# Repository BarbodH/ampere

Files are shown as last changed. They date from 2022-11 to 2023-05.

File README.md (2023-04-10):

# Ampere

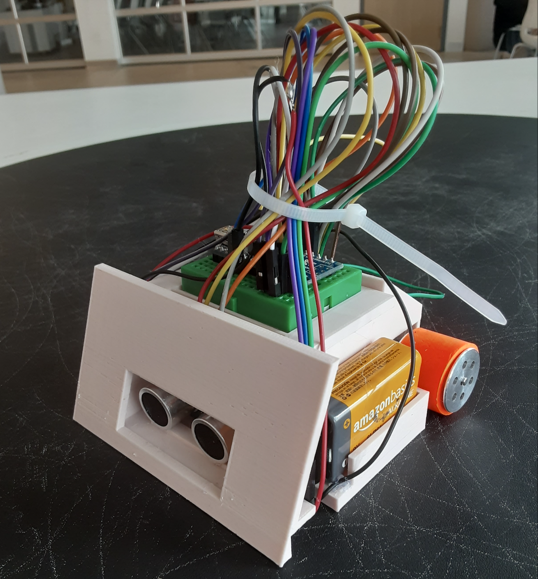
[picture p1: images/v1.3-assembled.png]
[](/images/v1.3-assembled.png)

Ampere is a self-driving 10×10 cm robot designed for [robot-sumo competitions](https://www.sumobot.ca/competition), analogous to the sport of sumo.

## Components

The robot utilizies the following pieces of electronic hardware:

  - [Arduino Nano](components/arduino-nano-v3.stl) (1×): main control unit using an ATmega328 microcontroller
  - [HC-SR04 ultrasonic sensor](components/hcsr04-ultrasonic-sensor.stl) (1×): utilized for detecting the opponent and initiating an attack
  - [QTR-1A reflectance sensor](components/qtr1a-reflectance-sensor.stl) (2×): utilized for keeping the robot inside the field using the floor color
  - [L298N motor driver](components/l298n-motor-driver.stl) (1×): utilized for controlling the movement of the 6V DC motors
  - [JSumo 6V DC motor](components/jsumo-dc-motor.stl) (2×): connect to the motor driver and handle mobility
  - 9V battery (2×): provide power for the robot

## Functionality

The functionality of the robot is divided into 3 layers of abstraction (ordered from lowest to highest):

  1. Libraries dealing with digital/analog input/output to the electronic hardware
      - [HC-SR04 ultrasonic sensor library](libraries/HCSR04_ultrasonic_sensor); developed by [gamegine](https://github.com/gamegine)
      - [QTR-1A reflectance sensor library](libraries/QTR1A_Reflectance_Sensor_Library); developed by me
      - [L298N motor driver library](libraries/L298N_Motor_Driver_Library); developed by me
  
  2. System classes providing a liaison between the microcontroller and hardware libraries through signals:
      - [Navigation system](microcontroller/NavigationSystem.h): utilizes the sensors to handle edge/opponent detection and produces boolean signals
      - [Motion control system](microcontroller/MotionControlSystem.h): utilizes the motor driver to handle various movement types

3. [Microcontroller](microcontroller/microcontroller.ino) Arduino file controlling the behaviour

Writing the entire program in the **microcontroller.ino** is also feasible.
However, dividing the program into multiple abstraction layers allows for better readability and debugging.

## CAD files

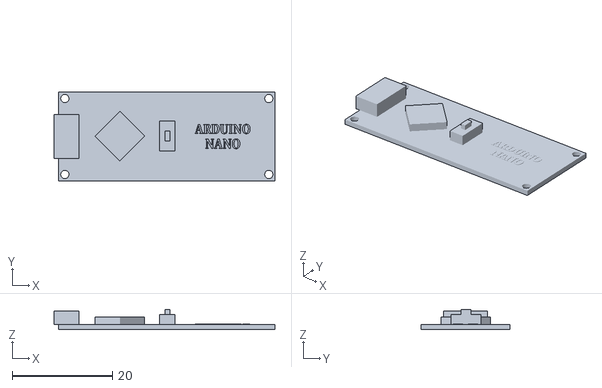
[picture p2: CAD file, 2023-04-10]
components/arduino-nano-v3.stl
44.1 x 17.8 x 4.00

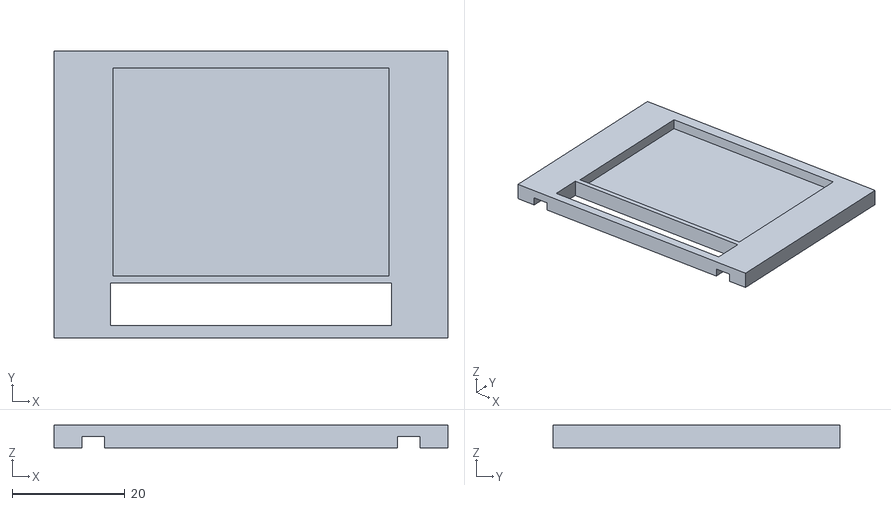
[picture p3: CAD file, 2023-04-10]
components/chassis/v1.4/roof.stl
70.0 x 51.0 x 4.00

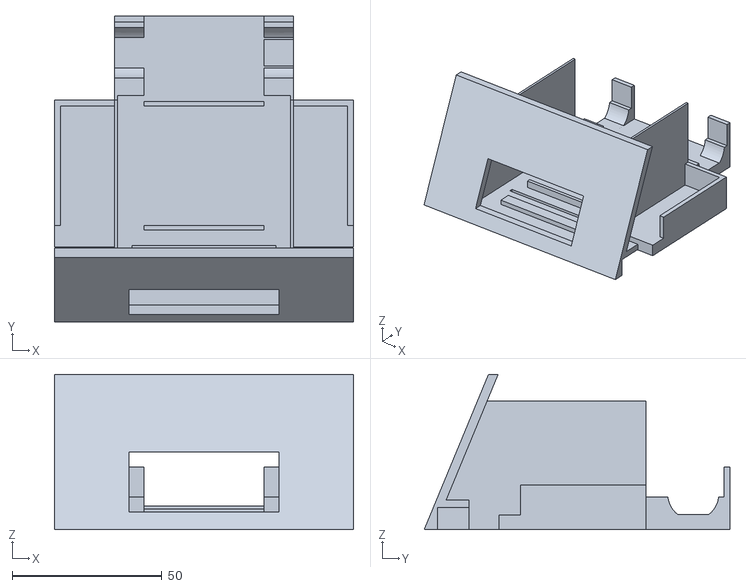
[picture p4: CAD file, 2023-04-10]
components/chassis/v1.4/chassis.stl
100.0 x 102.3 x 52.0

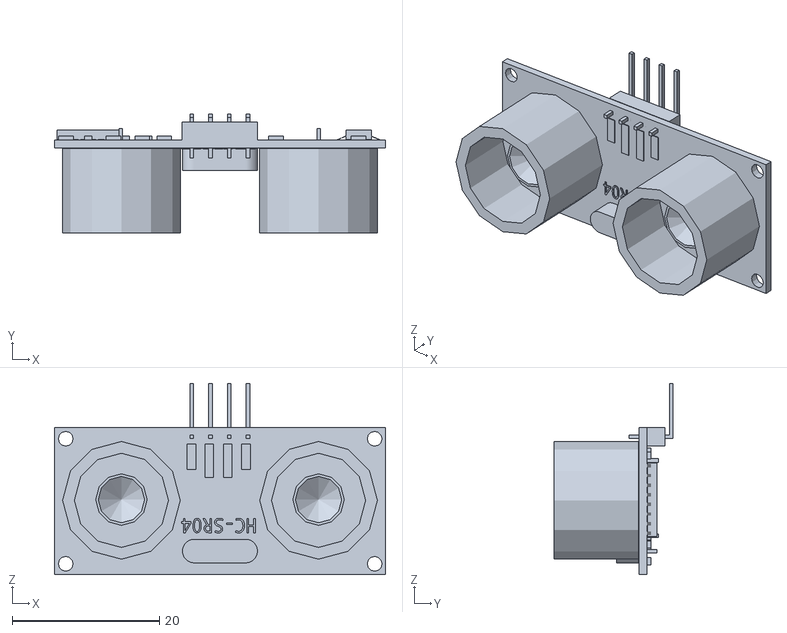
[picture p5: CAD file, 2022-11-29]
components/hcsr04-ultrasonic-sensor.stl
45.0 x 16.2 x 26.0

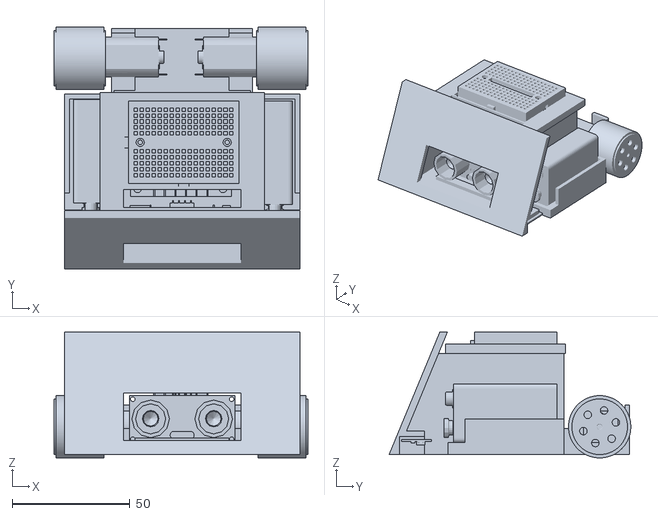
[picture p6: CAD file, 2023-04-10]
components/chassis/v1.4/sumobot.stl
108.0 x 102.8 x 53.5

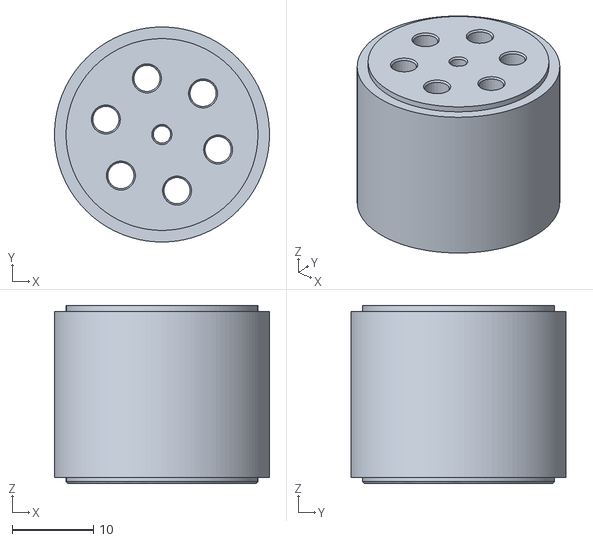
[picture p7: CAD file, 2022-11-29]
components/js7444-wheel.stl
26.5 x 26.5 x 22.0

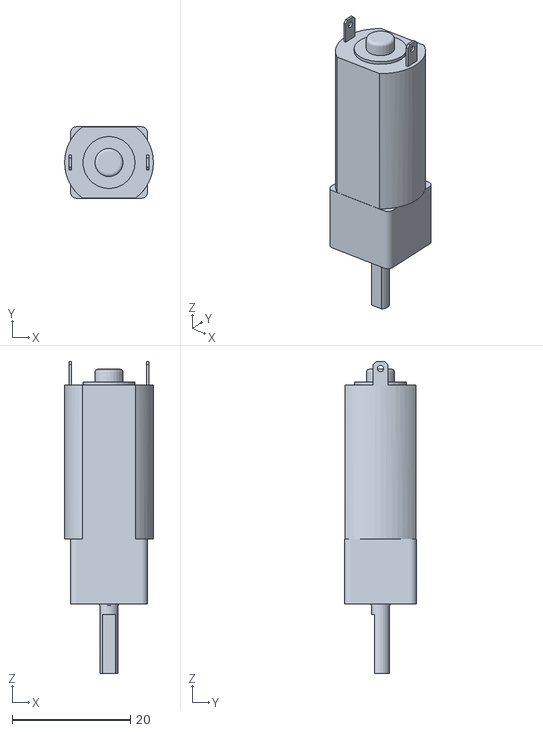
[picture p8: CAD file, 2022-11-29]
components/jsumo-dc-motor.stl
15.0 x 12.1 x 52.7

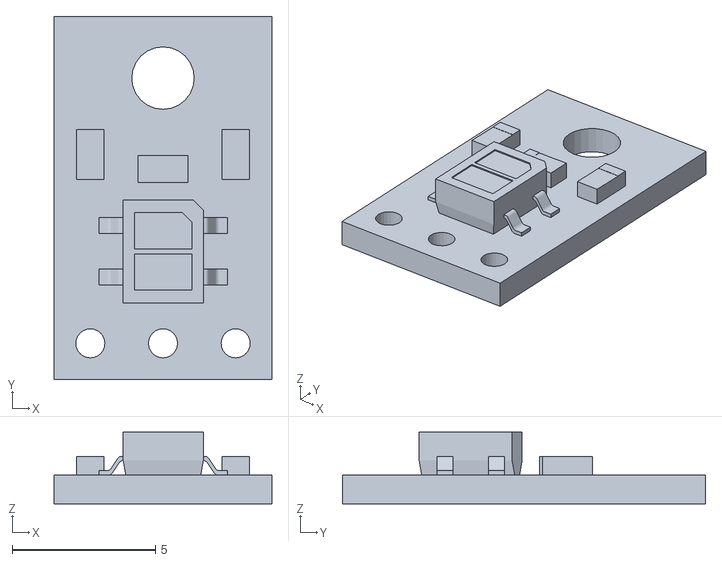
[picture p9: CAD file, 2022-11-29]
components/qtr1a-reflectance-sensor.stl
7.62 x 12.7 x 2.52

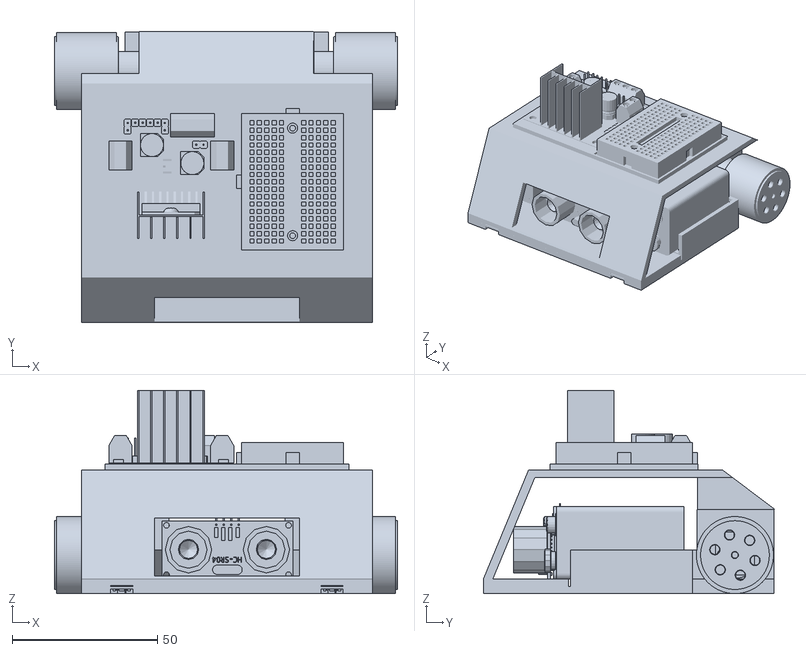
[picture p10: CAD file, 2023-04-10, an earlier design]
components/chassis/v1.0/sumobot.stl
118.0 x 100.2 x 69.9

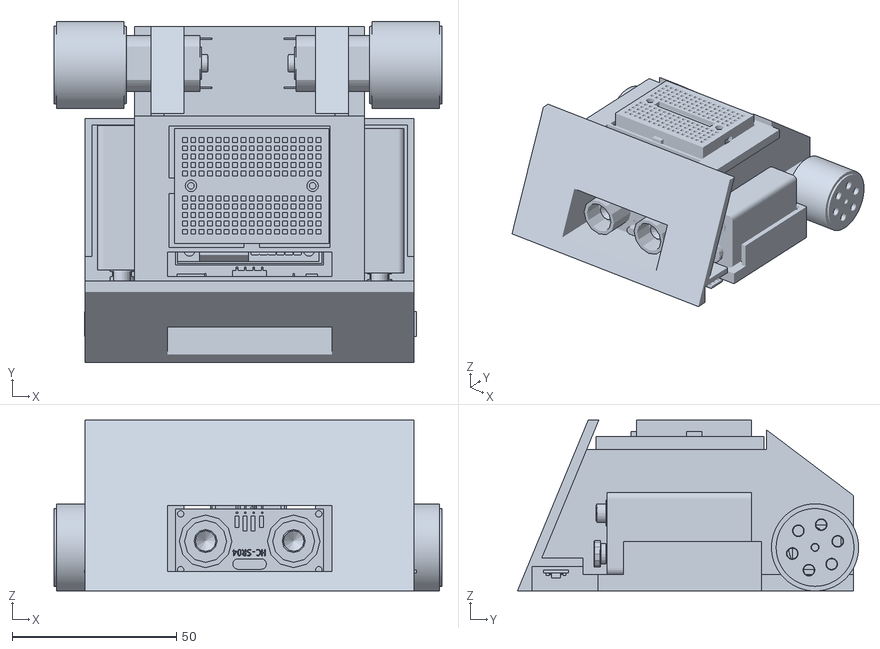
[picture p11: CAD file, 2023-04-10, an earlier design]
components/chassis/v1.1/sumobot.stl
118.0 x 103.8 x 52.0

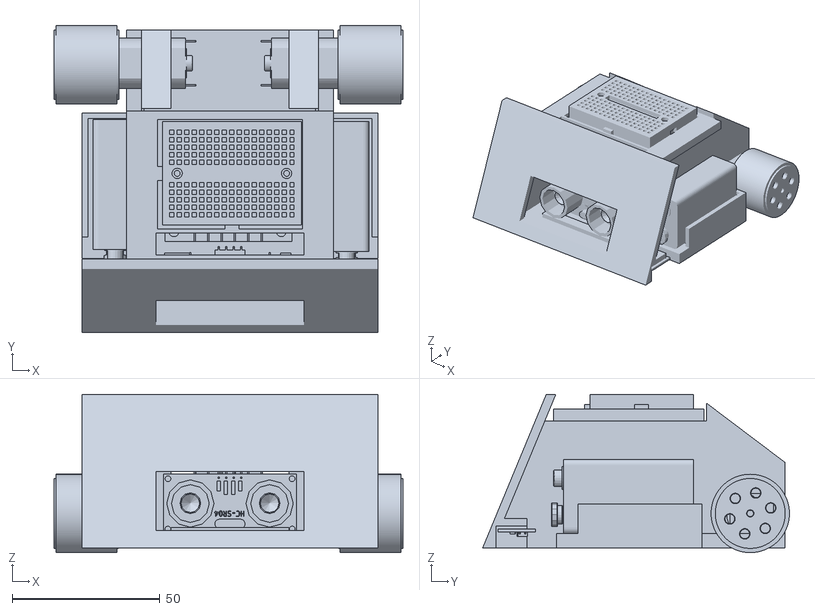
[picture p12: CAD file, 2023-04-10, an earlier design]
components/chassis/v1.2/sumobot.stl
118.0 x 103.8 x 53.5

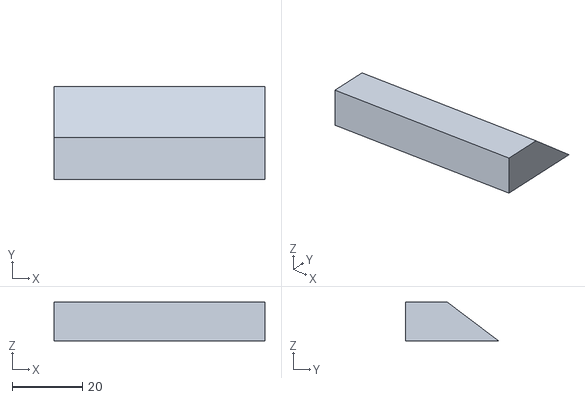
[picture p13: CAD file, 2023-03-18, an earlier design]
components/chassis/v1.0/roof-support.stl
60.0 x 26.5 x 11.0

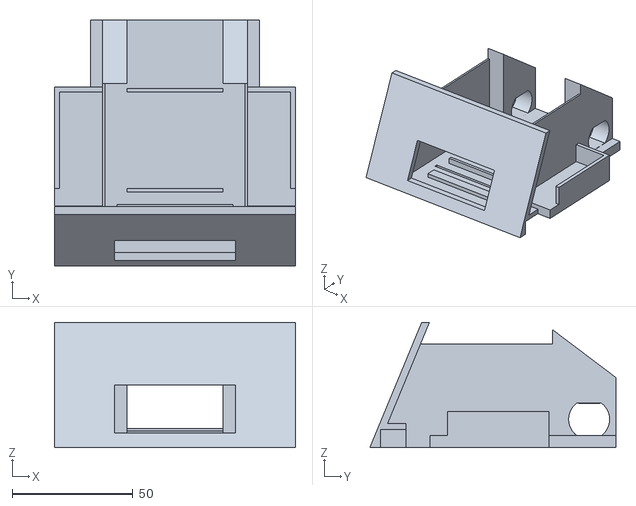
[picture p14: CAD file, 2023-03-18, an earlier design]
components/chassis/v1.2/chassis.stl
100.0 x 102.3 x 52.0

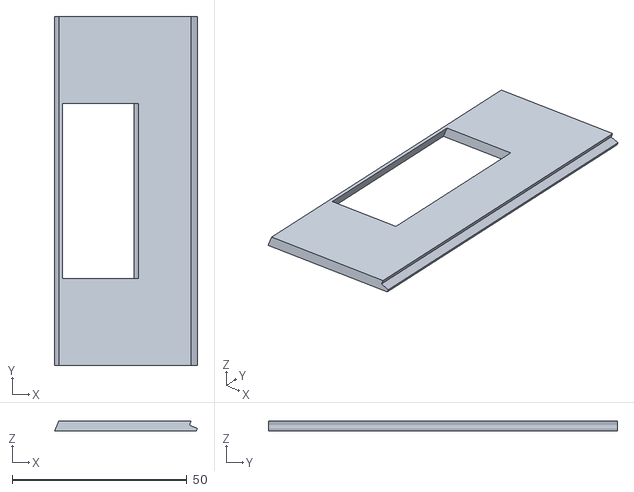
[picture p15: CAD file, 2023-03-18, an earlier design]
components/chassis/v1.0/front.stl
40.9 x 100.0 x 3.00

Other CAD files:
components/chassis/v1.3/sumobot.stl
components/chassis/v1.1/roof.stl
components/chassis/v1.3/roof.stl
components/chassis/v1.1/chassis.stl
components/chassis/v1.0/chassis.stl
components/chassis/v1.0/front-support.stl
components/chassis/v1.0/roof.stl
components/chassis/v1.2/roof.stl
components/chassis/v1.3/chassis.stl

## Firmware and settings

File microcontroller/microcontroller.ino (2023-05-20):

//////////////////// Control Systems ////////////////////

#include "NavigationSystem.h"
#include "MotionControlSystem.h"

//////////////////// Initialization ////////////////////

// macro-defined constants for pin values
#define PIN_ENABLE_A 2
#define PIN_ENABLE_B 3
#define PIN_INPUT_1 4
#define PIN_INPUT_2 5
#define PIN_INPUT_3 6
#define PIN_INPUT_4 7
#define TRIG_PIN 9
#define ECHO_PIN 10

// macro-defined constant for delay time (milliseconds) when changing movement mode
#define PING 250

// system instances
NavigationSystem navigationSystem;
MotionControlSystem motionControlSystem;

// initialization
void setup() {
  // navigation system initialization
  navigationSystem.setupSensorDist(TRIG_PIN, ECHO_PIN);
  navigationSystem.setupSensorRefl((const uint8_t[]){A0, A1});

  // motion control system initialization
  motionControlSystem.setupMotors(PIN_ENABLE_A, PIN_ENABLE_B,
    PIN_INPUT_1, PIN_INPUT_2, PIN_INPUT_3, PIN_INPUT_4);

  motionControlSystem.scan(ROTATE_CLOCKWISE);

  Serial.begin(9600);
}

//////////////////// Main Program ////////////////////

void loop()
{
  bool opponentDetected = navigationSystem.getStatusDist();
  bool *edgeExceeded = navigationSystem.getStatusRefl();

  // both edges exceeding the ring
  if (!edgeExceeded[0] && !edgeExceeded[1])
  {
    if (!opponentDetected)
    {
      if (motionControlSystem.isTriggered())
      {
        motionControlSystem.stop();
        delay(PING * 0.8);
        motionControlSystem.scan(ROTATE_CLOCKWISE);
      }
    }
    else
    {
      motionControlSystem.dash();
      delay(PING * 2);
    }
  }
  // left edge exceeding the ring
  else if (!edgeExceeded[0] && edgeExceeded[1])
  {
    if (!opponentDetected && motionControlSystem.isTriggered())
    {
      motionControlSystem.stop();
      delay(PING);
      motionControlSystem.scan(ROTATE_CLOCKWISE);
    }
    else
    {
      motionControlSystem.moveForwardCustom(ROTATE_MAX_SPEED, ROTATE_MAX_SPEED * 0.9);
      delay(PING * 1.75);
    }
  }
  // right edge exceeding the ring
  else if (edgeExceeded[0] && !edgeExceeded[1])
  {
    if (!opponentDetected && motionControlSystem.isTriggered())
    {
      motionControlSystem.stop();
      delay(PING);
      motionControlSystem.scan(ROTATE_COUNTERCLOCKWISE);
    }
    else
    {
      motionControlSystem.moveForwardCustom(ROTATE_MAX_SPEED * 0.9, ROTATE_MAX_SPEED);
      delay(PING * 1.75);
    }
  }
  // no edge exceeded; perfectly within the ring
  else
  {
    if (opponentDetected)
    {
      // since dash modifies state, store it in temp for determining delay time
      bool temp = motionControlSystem.isTriggered();
      if (!temp) motionControlSystem.dash();
      delay(temp ? PING * 1.8 : PING * 2);
    }
    else
    {
      if (motionControlSystem.isTriggered())
      {
        motionControlSystem.stop();
        delay(PING);
        motionControlSystem.scan(ROTATE_COUNTERCLOCKWISE);
      }
    }
  }
}

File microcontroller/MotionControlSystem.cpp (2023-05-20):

#include "MotionControlSystem.h"

MotionControlSystem::~MotionControlSystem()
{
  this->_motorL.~L298N();
  this->_motorR.~L298N();
  this->_triggered = false;
}

void MotionControlSystem::setupMotors(uint8_t pinEnableA, uint8_t pinEnableB,
  uint8_t pinInput1, uint8_t pinInput2, uint8_t pinInput3, uint8_t pinInput4)
{
  this->_motorL.init(pinEnableA, pinInput1, pinInput2);
  this->_motorR.init(pinEnableB, pinInput3, pinInput4);
}

void MotionControlSystem::moveCustom(bool directionL, bool directionR, uint8_t speedL, uint8_t speedR)
{
  this->_motorL.run(directionL, speedL);
  this->_motorR.run(directionR, speedR);
}

void MotionControlSystem::moveForwardCustom(uint8_t speedL, uint8_t speedR)
{
  this->moveCustom(ROTATE_COUNTERCLOCKWISE, ROTATE_CLOCKWISE, speedL, speedR);
}

void MotionControlSystem::moveBackwardCustom(uint8_t speedL, uint8_t speedR)
{
  this->moveCustom(ROTATE_CLOCKWISE, ROTATE_COUNTERCLOCKWISE, speedL, speedR);
}

void MotionControlSystem::moveForward(uint8_t speed)
{
  this->moveForwardCustom(speed, speed);
}

void MotionControlSystem::moveBackward(uint8_t speed)
{
  this->moveBackwardCustom(speed, speed);
}

void MotionControlSystem::rotateClockwise(uint8_t speed)
{
  this->moveCustom(ROTATE_COUNTERCLOCKWISE, ROTATE_COUNTERCLOCKWISE, speed, speed);
}

void MotionControlSystem::rotateCounterclockwise(uint8_t speed)
{
  this->moveCustom(ROTATE_CLOCKWISE, ROTATE_CLOCKWISE, speed, speed);
}

void MotionControlSystem::dash()
{
  this->moveForward(ROTATE_MAX_SPEED);
  this->_triggered = true;
}

void MotionControlSystem::scan(bool direction)
{
  if (direction) this->rotateClockwise(SCAN_ROTATION_SPEED);
  else this->rotateCounterclockwise(SCAN_ROTATION_SPEED);
  this->_triggered = false;
}

void MotionControlSystem::stop()
{
  this->_motorL.stop();
  this->_motorR.stop();
  this->_triggered = false;
}

bool MotionControlSystem::isTriggered()
{
  return this->_triggered;
}

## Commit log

2023-03-18 Added new chassis designs and initial codebase
    [chassis-roof.stl, chassis.stl, front-support.stl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]
2023-04-10 Added image, v1.4 components folder, and STL files
    [chassis.stl, roof.stl, sumobot.stl]
2023-04-10 Added Arduino Nano STL file
    [arduino-nano-v3.stl]
